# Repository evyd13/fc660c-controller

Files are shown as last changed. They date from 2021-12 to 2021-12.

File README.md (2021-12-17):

# FC660C Controller with USB-C

FC660C Controller with USB-C

## Features
- Fully compatible with keymaps for Hasu's FC660C controller
- USB-C port (required small case modification)
- ESD protection circuit

## Bill of materials (BOM)
Please have a look at the production files!

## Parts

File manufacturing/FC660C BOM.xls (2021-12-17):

FC660C Controller BOM
Manufacturer | Manufacturer Part Number (required) | Designator (required) | Qty (required) | Description (required) | Case | SMD ,BGA,LCC,OR TH | Top/Bottom | points (number of contacts the IC has in each board) | Total points (number of contacts per BOM line has) | Comment
Samsung Electro-Mechanics | CL21B104KBCNNNC | C1-C5 | 5 | 100nf capacitor | 0805 | SMD | Bottom
Samsung Electro-Mechanics | CL21A475KAQNNNE | C6 | 1 | 4.7uf capacitor | 0805 | SMD | Bottom
Samsung Electro-Mechanics | CL21A105KBCLNNC | C7, C9, C10 | 3 | 1uf capacitor | 0805 | SMD | Bottom
Samsung Electro-Mechanics | CL21B472KCANNNC | C8 | 1 | 4.7nF capacitor | 0805 | SMD | Bottom
Walsin Tech Corp | WR08X103JTL | R3, R4 | 2 | 10k ohm resistor | 0805 | SMD | Bottom
Walsin Tech Corp | WR08X220JTL | R1, R2 | 2 | 22 ohm resistor | 0805 | SMD | Bottom
Walsin Tech Corp | WR08X512JTL | R5, R6 | 2 | 5.1k ohm resistor | 0805 | SMD | Bottom
Walsin Tech Corp | WR08X105JTL | R7 | 1 | 1M ohm resistor | 0805 | SMD | Bottom
Microchip Tech | ATMEGA32U4-AU | U1 | 1 | Microcontroller | QFP-44 | SMD | Bottom |  |  | Do not substitute
STMicroelectronics | USBLC6-2SC6 | U2 | 1 | Diode ESD | SOT-23-6 | SMD | Bottom |  |  | Do not substitute
Murata Electronics | CSTNE16M0V530000R0 | X1 | 1 | Resonator |  | SMD | Bottom |  |  | Do not substitute
TLC Electronic | TLC-PSMD050 | F1 | 1 | PTC Fuse | 0805 | SMD | Bottom
Korean Hroparts Elec | TYPE-C-31-M-12 | J1 | 1 | USB-C Connector |  | SMD+THT | Bottom
Hirose | DF14-20P-1.25H(56) | J3 | 1 | Board to board connector |  | SMD | Bottom
Korean Hroparts Elec | K2-1187SQ-A4SW-06 | SW1 | 1 | Tactile switch |  | SMD | Bottom
Youtai Semiconductor Co., Ltd. | XC6206P332MR | U3 | 1 | Linear Voltage Regulator 3.3V | SOT-23 | SMD | Bottom

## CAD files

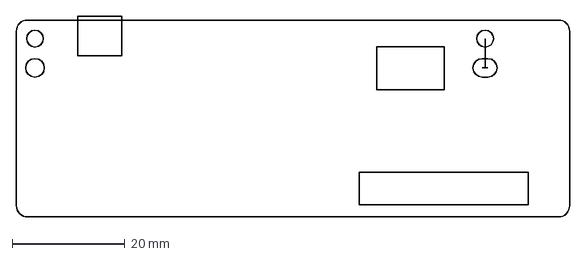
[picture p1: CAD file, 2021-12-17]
outline.dxf
98.2 x 35.7 mm

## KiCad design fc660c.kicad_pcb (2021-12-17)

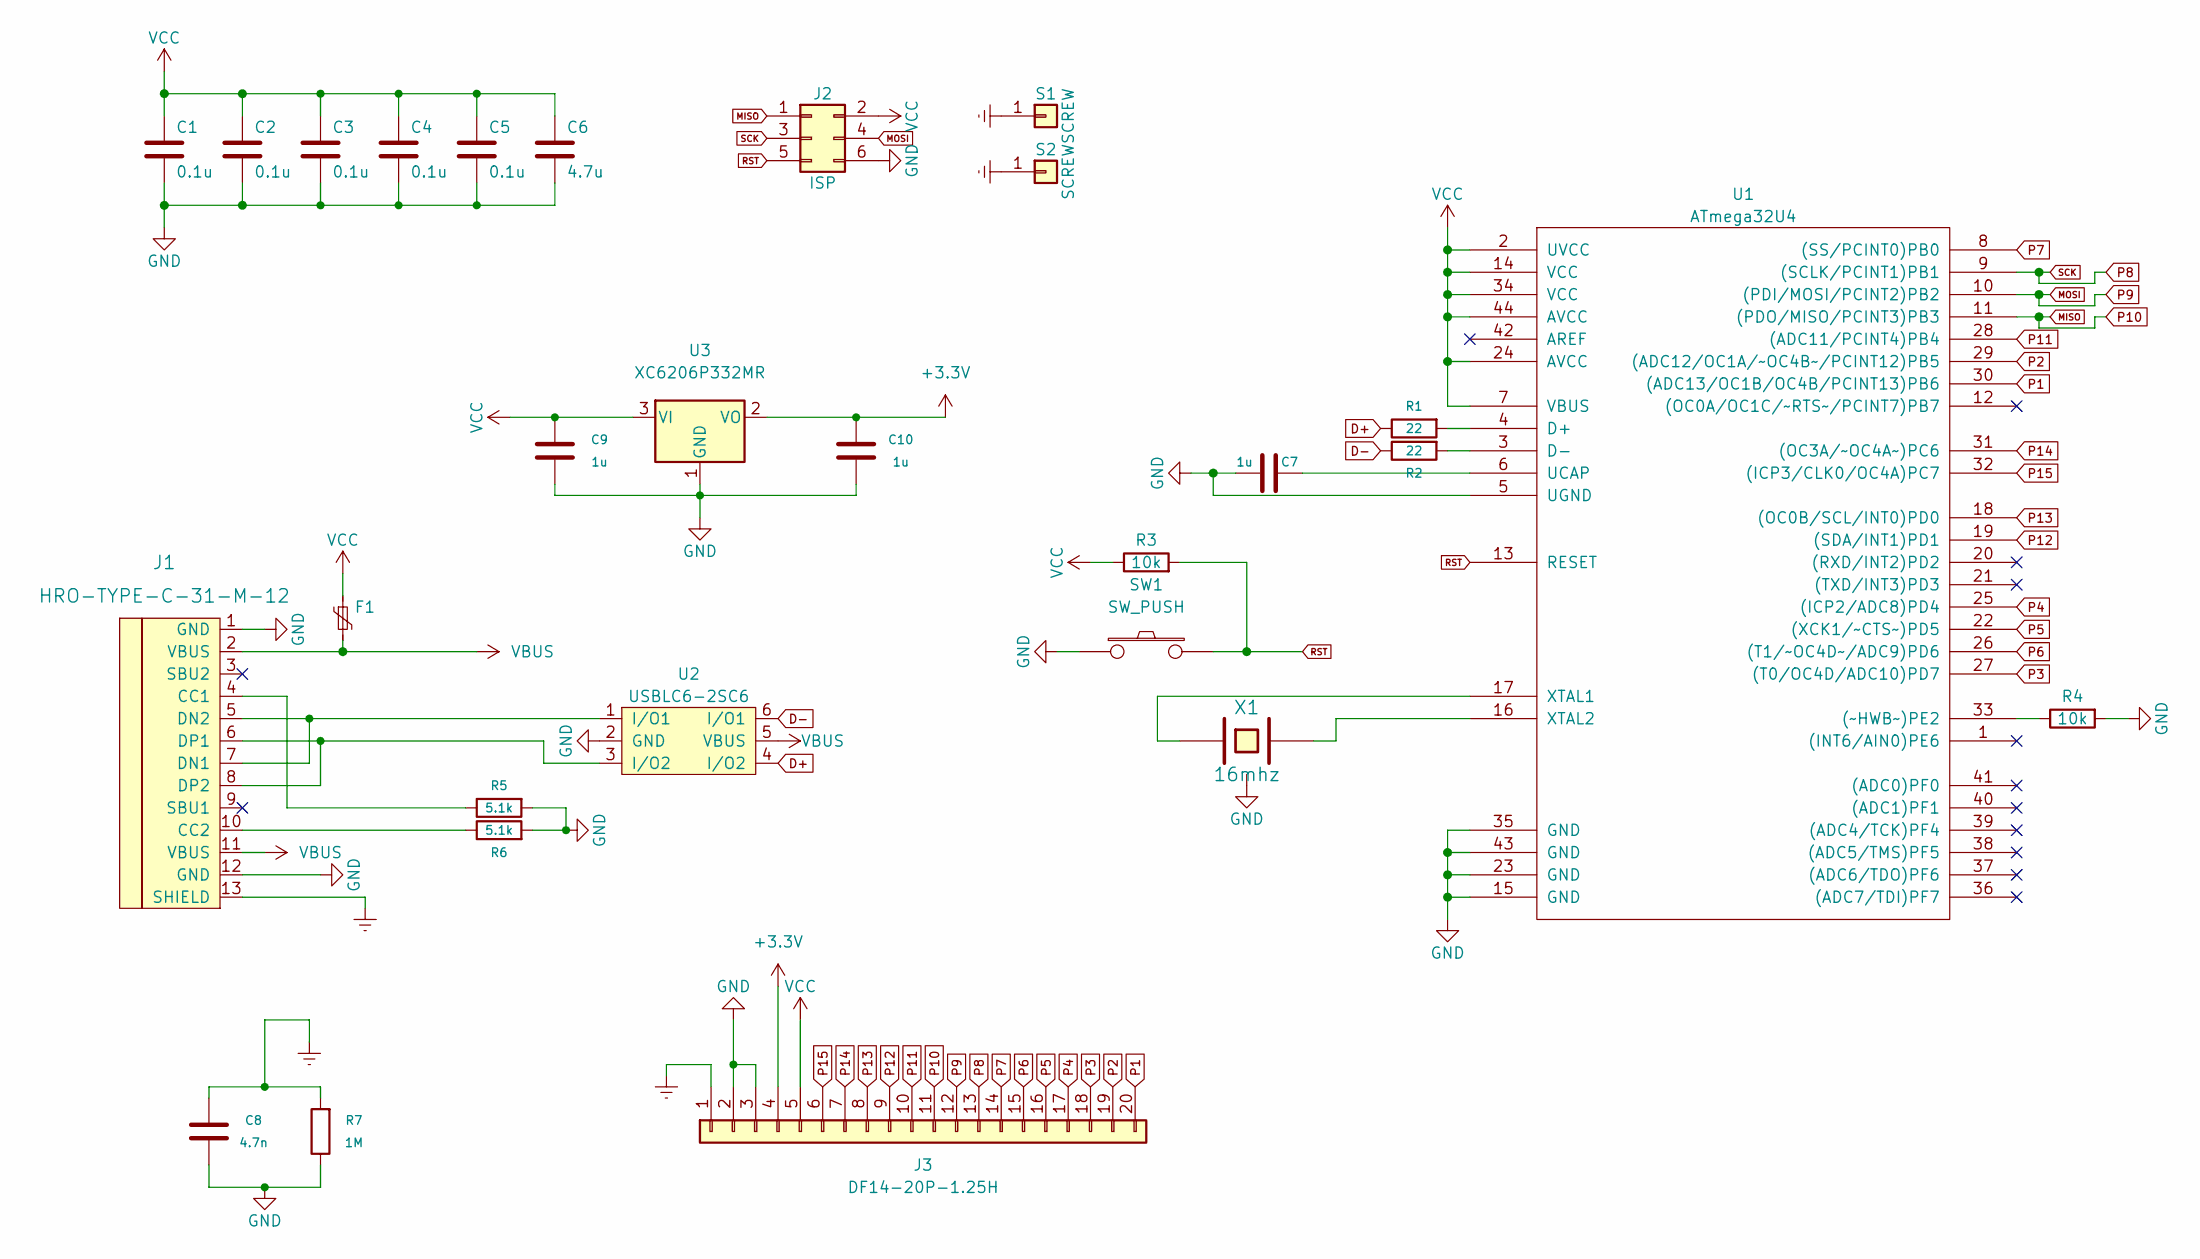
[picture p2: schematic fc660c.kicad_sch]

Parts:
C1, C2, C3, C4, C5: 0.1u; C_0805
C6: 4.7u; C_0805
C7, C9, C10: 1u; C_0805
C8: 4.7n; C_0805
F1: Polyfuse_Small; F_0805
J1: HRO-TYPE-C-31-M-12
J2: ISP; isp_standard
J3: DF14-20P-1.25H
R1, R2: 22; R_0805
R3, R4: 10k; R_0805
R5, R6: 5.1k; R_0805
R7: 1M; R_0805
S1, S2: SCREW; screw
SW1: SW_PUSH; SW_SPST_TL3342
U1: ATmega32U4; ATMEGA32U4
U2: USBLC6-2SC6
U3: XC6206P332MR; SOT-23
X1: 16mhz; Resonator_SMD_muRata_CSTNExxV-3Pin-p1.2

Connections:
+3V3: C10.1, J3.4, U3.2 (VO)
D+: R1.1, U2.4 (I/O2)
D-: R2.1, U2.6 (I/O1)
Earth: C8.1, J1.13 (SHIELD), J3.1, R7.2, S1.1, S2.1
GND: C1.2, C2.2, C3.2, C4.2, C5.2, C6.2, C7.2, C8.2, C9.2, C10.2, J1.1 (GND), J1.12 (GND), J2.6, J3.2, J3.3, R4.2, R5.2, R6.2, R7.1, SW1.1, U1.5 (UGND), U1.15 (GND), U1.23 (GND), U1.35 (GND), U1.43 (GND), U2.2 (GND), U3.1 (GND), X1.3
MISO: J2.1, J3.11, U1.11 ((PDO/MISO/PCINT3)PB3)
MOSI: J2.4, J3.12, U1.10 ((PDI/MOSI/PCINT2)PB2)
unnamed: C7.1, U1.6 (UCAP)
unnamed: J1.4 (CC1), R5.1
unnamed: J1.5 (DN2), J1.7 (DN1), U2.1 (I/O1)
unnamed: J1.6 (DP1), J1.8 (DP2), U2.3 (I/O2)
unnamed: J1.10 (CC2), R6.1
unnamed: R1.2, U1.4 (D+)
unnamed: R2.2, U1.3 (D-)
unnamed: R4.1, U1.33 ((~HWB~)PE2)
unnamed: U1.16 (XTAL2), X1.2
unnamed: U1.17 (XTAL1), X1.1
P1: J3.20, U1.30 ((ADC13/OC1B/OC4B/PCINT13)PB6)
P2: J3.19, U1.29 ((ADC12/OC1A/~OC4B~/PCINT12)PB5)
P3: J3.18, U1.27 ((T0/OC4D/ADC10)PD7)
P4: J3.17, U1.25 ((ICP2/ADC8)PD4)
P5: J3.16, U1.22 ((XCK1/~CTS~)PD5)
P6: J3.15, U1.26 ((T1/~OC4D~/ADC9)PD6)
P7: J3.14, U1.8 ((SS/PCINT0)PB0)
P8: J2.3, J3.13, U1.9 ((SCLK/PCINT1)PB1)
P11: J3.10, U1.28 ((ADC11/PCINT4)PB4)
P12: J3.9, U1.19 ((SDA/INT1)PD1)
P13: J3.8, U1.18 ((OC0B/SCL/INT0)PD0)
P14: J3.7, U1.31 ((OC3A/~OC4A~)PC6)
P15: J3.6, U1.32 ((ICP3/CLK0/OC4A)PC7)
RST: J2.5, R3.2, SW1.2, U1.13 (RESET)
VBUS: F1.2, J1.2 (VBUS), J1.11 (VBUS), U2.5 (VBUS)
VCC: C1.1, C2.1, C3.1, C4.1, C5.1, C6.1, C9.1, F1.1, J2.2, J3.5, R3.1, U1.2 (UVCC), U1.7 (VBUS), U1.14 (VCC), U1.24 (AVCC), U1.34 (VCC), U1.44 (AVCC), U3.3 (VI)

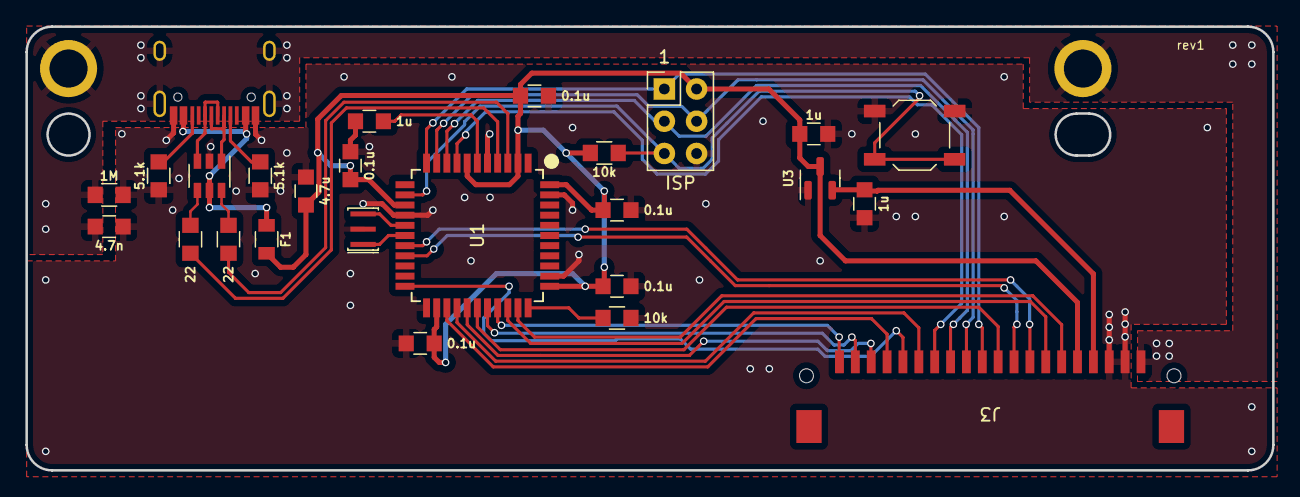
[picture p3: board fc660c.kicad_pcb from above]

Board: 2 copper layers, 98.2 x 35.0 mm, 28 parts (0 on the bottom side), 33 nets.
